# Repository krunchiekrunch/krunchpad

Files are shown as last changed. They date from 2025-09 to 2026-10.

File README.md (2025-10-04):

# krunchpad
A macropad powered by RP2040

# Images

| Schematic | PCB | 3D Preview | Case |
|:---:|:---:|:----:|:----:|
| Schematic | PCB | 3D-Front | Baseplate |
| | | 3D-Back | |

# Case

| Layout | Layout | Layout |
| :----: | :----: | :----: |
|  |  |  |

# BOM
| Qty  | Item | Notes | Cost (USD)| URL |
|---|---|---|---|---|
| 1 | Seeed Studio XIAO RP2040 | Microcontroller | $8.53 | [AE](https://www.aliexpress.com/item/1005006951950465.html) |
| 12 | THT 1N4148 Diode (DO-35 Footprint) | For switch matrix | $0.22 | [LCSC](https://www.lcsc.com/product-detail/C49318123.html) |
| 12 | MX-Style Switches | Mechanical key switches | $3.89 | [AE](https://www.aliexpress.com/item/1005009249474760.html) |
| 1 | EC11 Rotary Encoder | Volume control | $2.42 | [AE](https://www.aliexpress.com/item/1005008413622715.html) |
| 1 | 0.91" OLED Display | | $1.63 | [AE](https://www.aliexpress.com/item/32810205605.html) |
| 12 | Blank DSA Keycaps | | | |
| 5 | M3x5mmx4mm Heatset Inserts (W*H) | For mounting | $1.79 | [AE](https://www.aliexpress.com/item/1005007640664497.html) |
| 6 | M3 Screws (5.6mm Max) | For case assembly | $1.53 | [AE](https://www.aliexpress.com/item/1005003670389142.html) |
|------|------------------------------------|---------------------------|-----------|---------|
| 1 | Soldering Iron + Solder | Tools | $18.00 | |
| 1 | 3D Printed Case | Custom enclosure | $3.00 | |
| 1 | PCB | | $1.80 | |
|------|------------------------------------|---------------------------|-----------|---------|
| 2 | 2.54mm 4POS Header (Included) | OLED Mounting | | |
| 2 | 2.54mm 4POS Socket | OLED Mounting | $0.43 | [LCSC](https://www.lcsc.com/product-detail/C7509546.html) |
| 2 | 2.54mm 7POS Header (Included) | MCU Mounting | | |
| 2 | 2.54mm 7POS Socket | MCU Mounting | $0.45 | [LCSC](https://www.lcsc.com/product-detail/C25503116.html) |
| 12 | Kailh MX Hotswap Socket (Optional) | Hotswapping for switches  | $2.92 | [AE](https://www.aliexpress.com/item/1005007052649640.html) |
|------|------------------------------------|---------------------------|-----------|---------|

# Cases
- V1

Simple base plate with slots for heatset inserts

- V1.1

Added holes for the PCB to sit flush with the case where there are THT componants

- V1.2

Added a support knob to support the PCB in the center of the case

- V1.3

Added slots for the socket for the MCU

Removed the curved corners for the holes

A badge of a Cerberus and a raccoon laughing together, with the text "HIGHWAY" and "HACK CLUB" beside them.

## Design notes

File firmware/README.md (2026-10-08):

# CircuitPython (Tested with 10.3.1)

# Dependencies
- KMK
- [Adafruit CPY SSD1306 lib](https://github.com/adafruit/Adafruit_CircuitPython_DisplayIO_SSD1306/releases) (Download `adafruit-circuitpython-displayio-ssd1306-x.x-mpy-x.x.x.zip`

Unzip and move `/lib/adafruit_displayio_ssd1306.mpy` to `/lib` of your microcontroller

- [Adafruit CPY DIsplay Text lib](https://github.com/adafruit/Adafruit_CircuitPython_Display_Text/releases) (Download `adafruit-circuitpython-display-text-x.x-mpy-x.x.x.zip`

Unzip and move `/lib/adafruit_display_text` to `/lib` of your microcontroller

Download and move to the root of the microcontroller storage

# File structure

```
CIRCUITPY/
├─ kmk/
│  ├─ ...
├─ lib/
│  ├─ adafruit_display_text/
│  │  ├─ ...
│  ├─ adafruit_displayio_ssd1306.mpy
├─ main.py
├─ boot.py
```

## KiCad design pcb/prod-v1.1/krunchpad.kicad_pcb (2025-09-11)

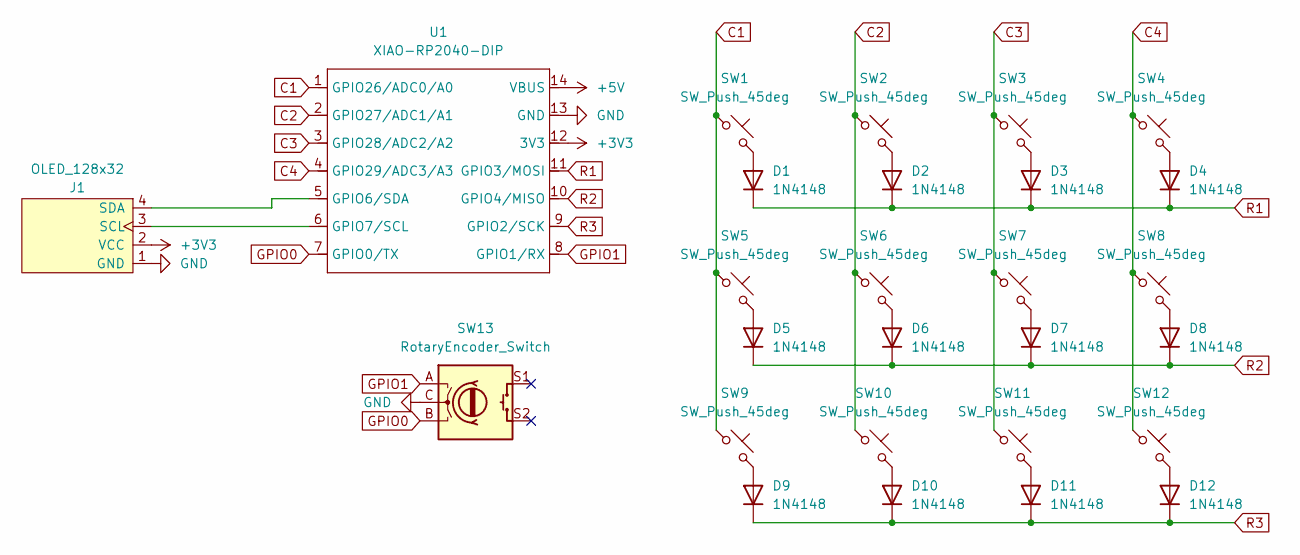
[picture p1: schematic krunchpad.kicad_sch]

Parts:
D1, D2, D3, D4, D5, D6, D7, D8, D9, D10, D11, D12: 1N4148; D_DO-35_SOD27_P7.62mm_Horizontal
J1: OLED_128x32; SSD1306-0.91-OLED-4pin-128x32
SW1, SW2, SW3, SW4, SW5, SW6, SW7, SW8, SW9, SW10, SW11, SW12: SW_Push_45deg; dual-hotswap_MX
SW13: RotaryEncoder_Switch; RotaryEncoder_Alps_EC11E-Switch_Vertical_H20mm
U1: XIAO-RP2040-DIP

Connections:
+3V3: J1.2 (VCC), U1.12 (3V3)
+5V: U1.14 (VBUS)
C1: SW1.1, SW5.1, SW9.1, U1.1 (GPIO26/ADC0/A0)
C2: SW2.1, SW6.1, SW10.1, U1.2 (GPIO27/ADC1/A1)
C3: SW3.1, SW7.1, SW11.1, U1.3 (GPIO28/ADC2/A2)
C4: SW4.1, SW8.1, SW12.1, U1.4 (GPIO29/ADC3/A3)
GND: J1.1 (GND), SW13.C, U1.13 (GND)
GPIO0: SW13.B, U1.7 (GPIO0/TX)
GPIO1: SW13.A, U1.8 (GPIO1/RX)
unnamed: D1.2 (A), SW1.2
unnamed: D2.2 (A), SW2.2
unnamed: D3.2 (A), SW3.2
unnamed: D4.2 (A), SW4.2
unnamed: D5.2 (A), SW5.2
unnamed: D6.2 (A), SW6.2
unnamed: D7.2 (A), SW7.2
unnamed: D8.2 (A), SW8.2
unnamed: D9.2 (A), SW9.2
unnamed: D10.2 (A), SW10.2
unnamed: D11.2 (A), SW11.2
unnamed: D12.2 (A), SW12.2
unnamed: J1.3 (SCL), U1.6 (GPIO7/SCL)
unnamed: J1.4 (SDA), U1.5 (GPIO6/SDA)
R1: D1.1 (K), D2.1 (K), D3.1 (K), D4.1 (K), U1.11 (GPIO3/MOSI)
R2: D5.1 (K), D6.1 (K), D7.1 (K), D8.1 (K), U1.10 (GPIO4/MISO)
R3: D9.1 (K), D10.1 (K), D11.1 (K), D12.1 (K), U1.9 (GPIO2/SCK)

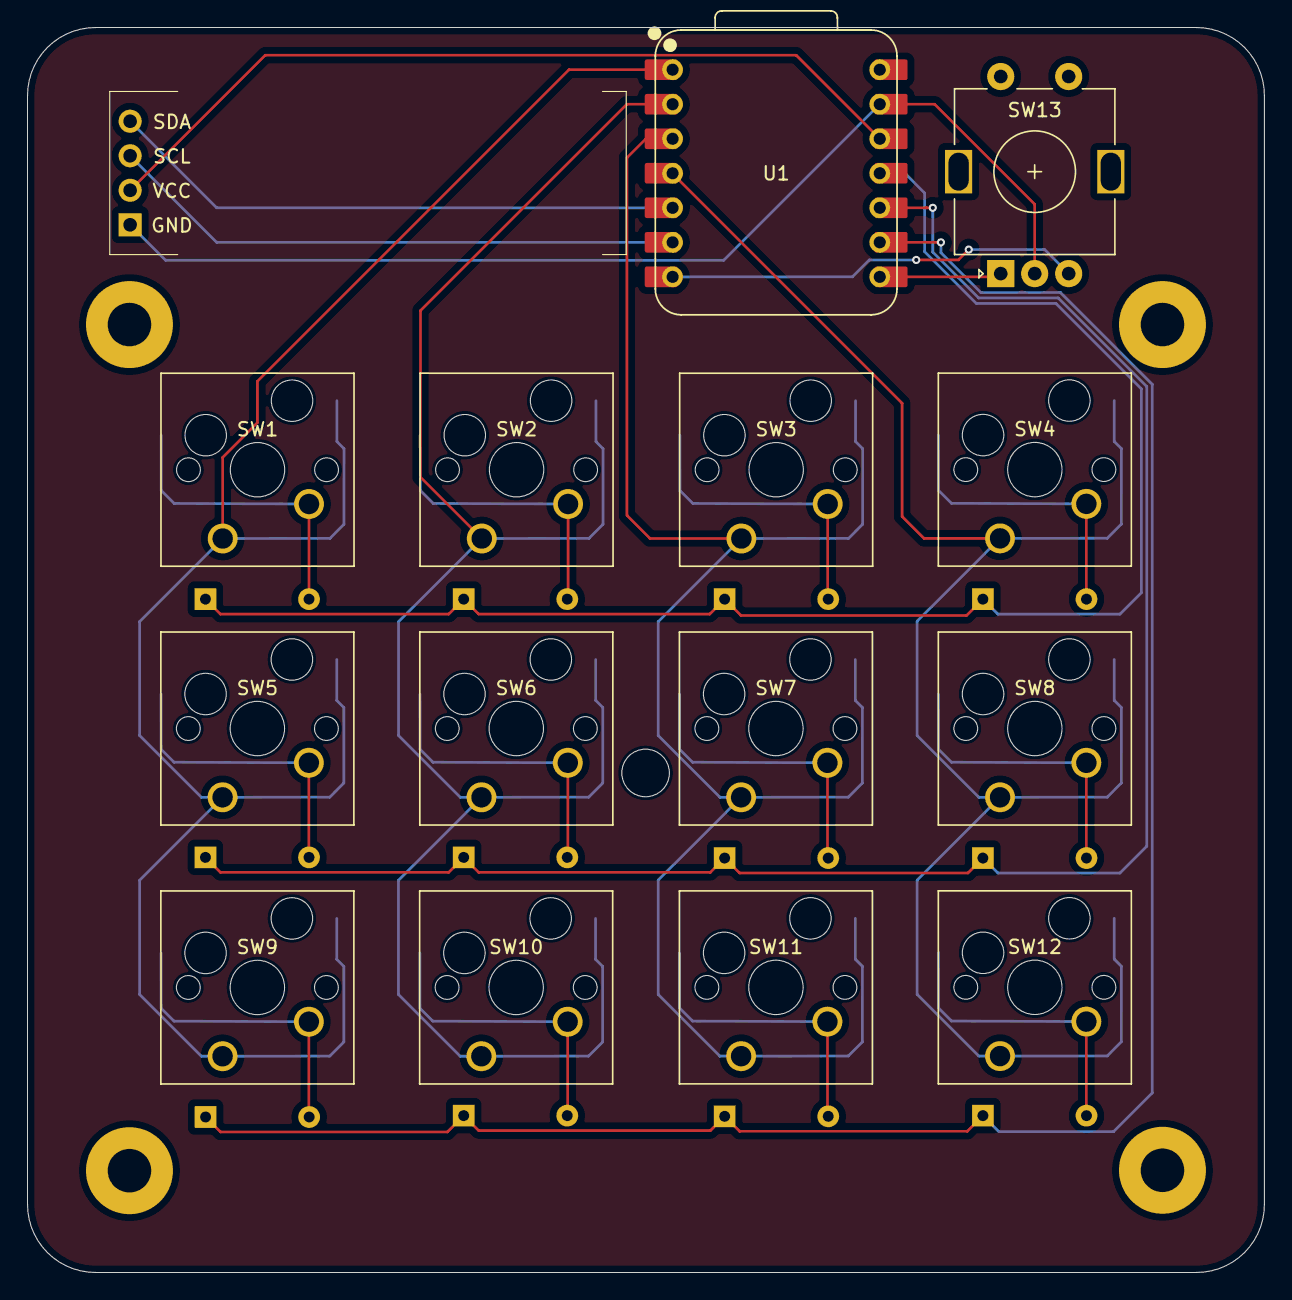
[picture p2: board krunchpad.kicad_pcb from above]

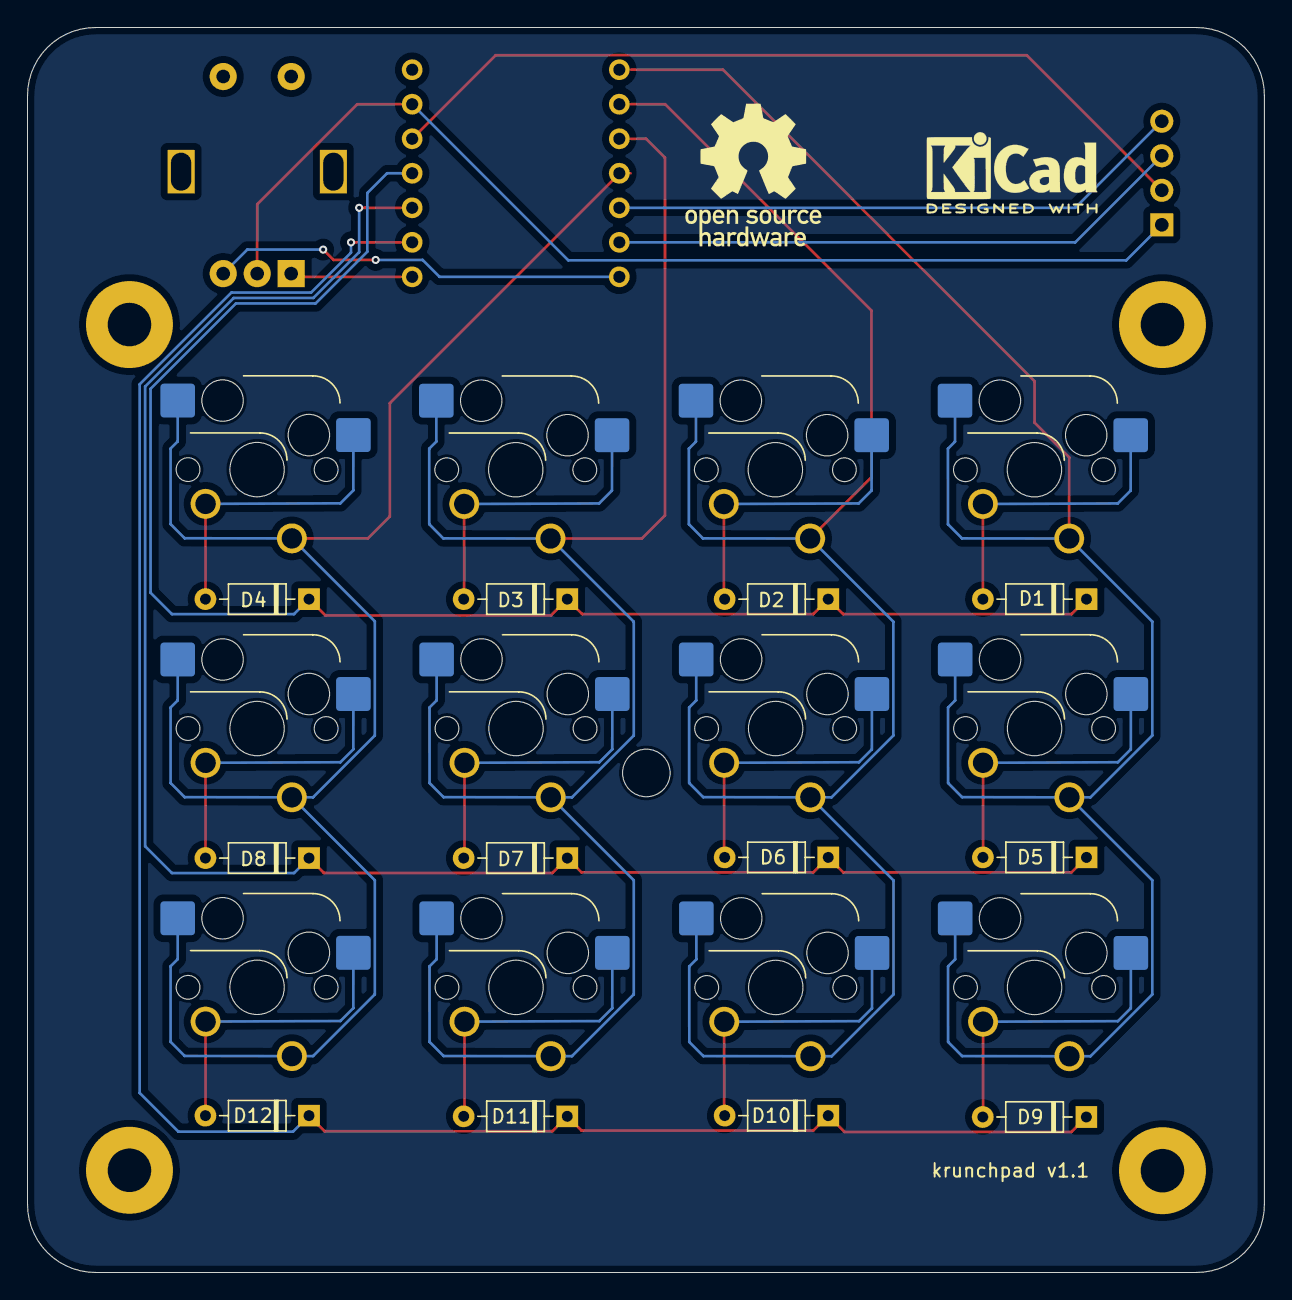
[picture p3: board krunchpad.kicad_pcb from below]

Board: 2 copper layers, 91.0 x 91.6 mm, 28 parts (13 on the bottom side), 25 nets.

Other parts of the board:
logo1: KiCad-Logo2_5mm_SilkScreen

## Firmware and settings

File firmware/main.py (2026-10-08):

import board
from kmk.kmk_keyboard import KMKKeyboard
from kmk.scanners.keypad import MatrixScanner
from kmk.keys import KC
from kmk.scanners import DiodeOrientation
from kmk.extensions.display import Display, TextEntry, ImageEntry
from kmk.extensions.display.ssd1306 import SSD1306
from kmk.modules.macros import Macros, Press, Release, Tap, Delay
from kmk.modules.mouse_keys import MouseKeys
from kmk.extensions.media_keys import MediaKeys
from kmk.modules.encoder import EncoderHandler
from kmk.modules.layers import Layers
from kmk.modules.tapdance import TapDance

keyboard = KMKKeyboard()
macros = Macros()
mouse = MouseKeys()
encoder_handler = EncoderHandler()
tapdance = TapDance()
tapdance.tap_time = 250
keyboard.modules.append(macros)
keyboard.modules.append(MouseKeys())
keyboard.extensions.append(MediaKeys())
keyboard.modules.append(encoder_handler)
keyboard.modules.append(Layers())
keyboard.modules.append(tapdance)

# matrix
keyboard.row_pins = (board.D10, board.D9, board.D8)
keyboard.col_pins = (board.D0, board.D1, board.D2, board.D3)
keyboard.diode_orientation = DiodeOrientation.COL2ROW

_______ = KC.TRNS
xxxxxxx = KC.NO
xxxx = KC.NO
Fn = KC.MO(1)

RST = KC.LCTRL(KC.SPACE)
MV = KC.LSHIFT(KC.SPACE)
RSTMV = KC.TD(RST, MV)

LWIN = KC.LALT(KC.N1)
RWIN = KC.LALT(KC.N3)
FO = KC.LALT(KC.N9)

FULL = KC.LALT(KC.N7)
OVH = KC.LALT(KC.N8)
PED = KC.LALT(KC.N5)
EFB = KC.LALT(KC.N0)

keyboard.keymap = [
    [
        KC.F13, KC.F14, KC.F15, KC.F16,
        RST,    LWIN,   RWIN,   FO,
        FULL,   OVH,    PED,    EFB,
    ],
]

# volume knob
encoder_handler.pins = ((board.D6, board.D7),)
encoder_handler.map = [
    ((KC.VOLD, KC.VOLU),),   # Volume control
    ]

# 128x32 OLED display
display = Display(
    display=SSD1306(sda=board.D4, scl=board.D5),
    entries=[
        TextEntry(text="""
REC  CLIP TGLE SS
RST  LWIN RWIN FO
FULL OVHD PED  EFB
        """),
    ],
    width=128,
    height=32,
    brightness=0.1,
)
keyboard.extensions.append(display)

if __name__ == '__main__':
    keyboard.go()

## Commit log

2025-09-11 krunchpad v1.1 + plate
    [krunchpad-plate.kicad_pcb, krunchpad-plate.kicad_sch, krunchpad.kicad_pcb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]
2025-10-02 BOM source update
2025-11-16 rotary encoder works, disabled neopixel
2025-11-19 Revise README with CircuitPython requirements
    Updated README to include dependencies and file structure.
